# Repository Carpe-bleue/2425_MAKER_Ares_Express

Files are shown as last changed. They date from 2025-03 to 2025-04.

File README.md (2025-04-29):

# 2425_MAKER_Ares_Express
Depository for the "Ares Express" project, within the framework of the Maker option of ENSEA led by M.Papazoglou

Video récapitulative : https://www.youtube.com/watch?v=NGvs9T8YtXU

# Description
The idea of this project is to build a miniature train on rails. It would integrate features like LEDs, sound, moving parts, screen(s), storage capacity, and remote controlled.
The PCB and motors would be placed in the head Wagon in the front and other wagons would be attached to it and could be replaced easily so we would switch them depending what we want the train to do (adding wagons that can contain things or just fun or decorative wagons).
Screenshot from 2025-01-19 17-37-25
from the following video : "https://youtu.be/WkL9zbtfKDo?si=UJvP77D1sXWMVc81"

# For now :
https://github.com/user-attachments/assets/c41e23c4-729e-4bb9-a937-4c54bc4e76e5

# Ideas

- wheels :
- Screenshot from 2025-01-19 16-12-46

- module HC-SR04 (detect obstacles) :
- Screenshot from 2025-01-18 23-15-40
  
- Steam ? :
- Screenshot from 2025-01-18 23-14-02

PCB : moteurs (x2 minimum), battery, communication module (bluetooth ?), ultrasound module, screen, actuators, module that make sound ?, LEDs, electro-magnets ?, accelerometers, 

electromagnets to attach/detach wagons !
Camera ?

- details : angry eyebrows, ares logo, small characters ?
Difficult ideas : A claw to move an object from the tracks, mapping room with lidar, putting tracks before itself, Stations

# Planning :

- 3d Model, 1st wagon : 23 janvier
- Printing 1st Wagon : 23-27 janvier
- PCB : 10 février

- Vacation : Models for Head wagon and rails

- 1st rail (laser) : 3 mars
- Head wagon model : 10 mars
- Printing head Wagon : 13 mars
- Test of head wagon with PCB : 17 mars 
- Complete track (laser cut wood) : 20 mars-24 mars
- Soft (screen, LEDs, communication) : 27 mars - 4 avril

Module Hc-sr04 :


Module Hc-05 : 


Module Caméra ? :


Potentially useful regulator : 


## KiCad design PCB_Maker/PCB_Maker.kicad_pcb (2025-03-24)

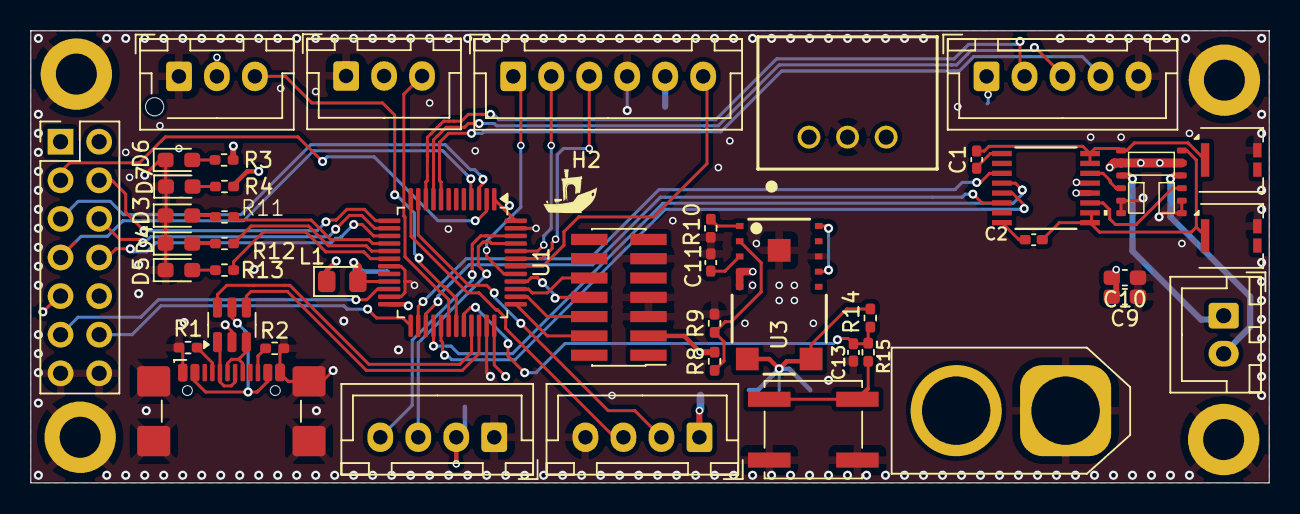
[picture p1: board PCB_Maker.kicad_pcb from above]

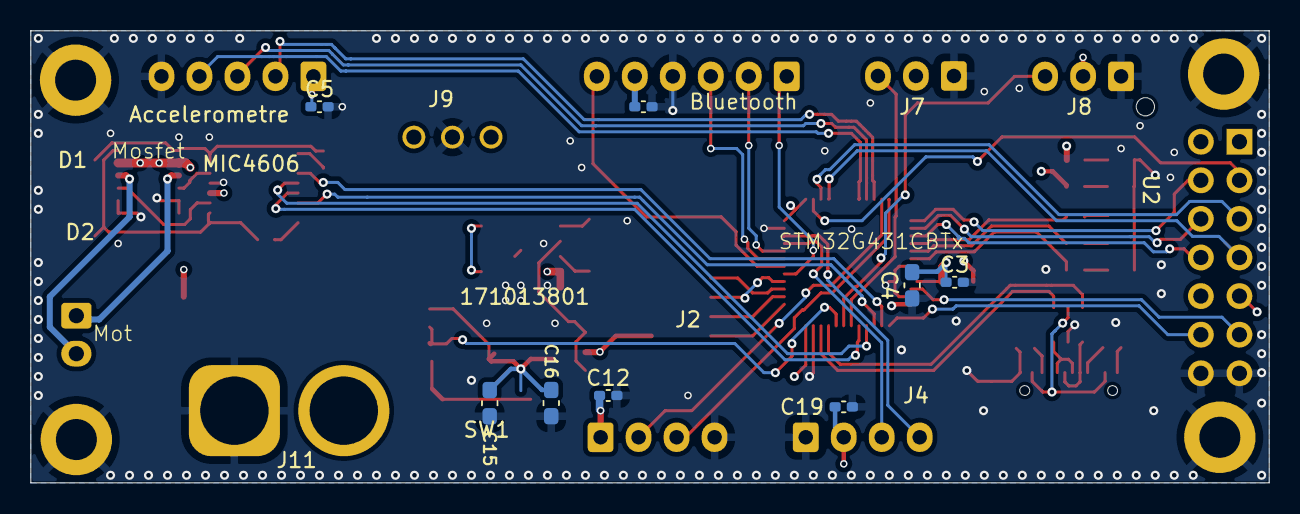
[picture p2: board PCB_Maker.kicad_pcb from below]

Board: 4 copper layers, 81.5 x 29.8 mm, 56 parts (8 on the bottom side), 63 nets.

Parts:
C1, C2, C5, C6, C11, C12, C19: 1u; C_0402_1005Metric_Pad0.74x0.62mm_HandSolder
C3, C13: 10n; C_0402_1005Metric_Pad0.74x0.62mm_HandSolder
C4: 1u; C_0603_1608Metric_Pad1.08x0.95mm_HandSolder
C9: 22u; C_0603_1608Metric_Pad1.08x0.95mm_HandSolder
C10: 10u; C_0603_1608Metric_Pad1.08x0.95mm_HandSolder
C15, C16: 100n; C_0603_1608Metric_Pad1.08x0.95mm_HandSolder
D1, D2: D_Zener; Littelfuse_PolyZen-LS
D3, D4, D5: LED_GREEN; LED_0603_1608Metric_Pad1.05x0.95mm_HandSolder
D6: RED_LED_5V; LED_0603_1608Metric_Pad1.05x0.95mm_HandSolder
D7: RED_LED_3.3V; LED_0603_1608Metric_Pad1.05x0.95mm_HandSolder
H1, H2, H3, H4: MountingHole_Pad; MountingHole_2.7mm_M2.5_DIN965_Pad
J1: USB_C_Receptacle_USB2.0_16P; USB_C_Receptacle_GCT_USB4110
J2: Conn_ST_STDC14; PinHeader_2x07_P1.27mm_Vertical_SMD
J3: Conn_01x02; JST_XH_B2B-XH-A_1x02_P2.50mm_Vertical
J4, J5: Conn_01x04; JST_XH_B4B-XH-A_1x04_P2.50mm_Vertical
J6: Conn_01x05; JST_XH_B5B-XH-A_1x05_P2.50mm_Vertical
J7: Conn_01x03; JST_XH_B3B-XH-A_1x03_P2.50mm_Vertical
J8: Conn_01x03; JST_XH_B3B-XH-AM_1x03_P2.50mm_Vertical
J9: 173010542; 173013542
J10: Conn_02x07_Odd_Even; PinHeader_2x07_P2.54mm_Vertical
J11: Conn_01x02; AMASS_XT60-F_1x02_P7.20mm_Vertical
J12: Conn_01x06; JST_XH_B6B-XH-A_1x06_P2.50mm_Vertical
L1: 39n; LED_0805_2012Metric_Pad1.15x1.40mm_HandSolder
MIC4606: TSSOP16_TS_MCH_MIS
Mosfet_canal_N1: FDMQ86530L
R1, R2: 5.1k; R_0402_1005Metric_Pad0.72x0.64mm_HandSolder
R3: 3k6; R_0402_1005Metric_Pad0.72x0.64mm_HandSolder
R4, R11, R12, R13: 1k6; R_0402_1005Metric_Pad0.72x0.64mm_HandSolder
R8: 287k; R_0402_1005Metric_Pad0.72x0.64mm_HandSolder
R9: 137k; R_0402_1005Metric_Pad0.72x0.64mm_HandSolder
R10: 5.6k; R_0402_1005Metric_Pad0.72x0.64mm_HandSolder
R14, R15: 10k; R_0402_1005Metric_Pad0.72x0.64mm_HandSolder
SW1: SW_Push; SW_Push_1P1T_NO_CK_KSC6xxJ
U1: STM32G431CBTx; LQFP-48_7x7mm_P0.5mm
U2: USBLC6-2SC6; SOT-23-6
U3: 171013801; 171023801

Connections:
+3.3V: C12.1, C15.1, C16.1, C19.1, J2.3 (VCC), J4.2, J5.1, J10.9, J10.10, L1.1, R4.1, R8.1, R14.1, U1.1 (VBAT), U1.24 (VDD), U1.36 (VDD), U1.48 (VDD), U3.6, U3.7
+3.3VA: C3.1, C4.1, L1.2, U1.21 (VDDA)
+5V: C5.1, C6.1, J6.1, J7.2, J8.2, J9.3 (VOUT), J10.1, J10.2, J12.5, R3.1
/ADC_accelerometer_X: J6.2, U1.10 (PA2)
/ADC_accelerometer_Y: J6.3, U1.9 (PA1)
/ADC_accelerometer_Z: J6.4, U1.8 (PA0)
/D+: J1.A6 (D+), J1.B6 (D+), U2.3 (I/O2)
/D-: J1.A7 (D-), J1.B7 (D-), U2.1 (I/O1)
/EN_Bluetooth: J12.6, U1.42 (PB5)
/Echo_HC_SR04: J5.3, U1.12 (PA4)
/GPIO_filtered: C13.1, R14.2, R15.1, U1.32 (PA10)
/I2C1_SCL: J4.3, U1.45 (PB8)
/I2C1_SDA: J4.4, U1.46 (PB9)
/PA_5: J10.4, U1.13 (PA5)
/PA_6: J10.6, U1.14 (PA6)
/PA_7: J10.8, U1.15 (PA7)
/PB0_LED_1: R11.1, U1.16 (PB0)
/PB1_LED_2: R12.1, U1.17 (PB1)
/PB2_LED_3: R13.1, U1.18 (PB2)
/PB_10: J10.11, U1.22 (PB10)
/PB_11: J10.12, U1.25 (PB11)
/PC_13: J10.3, U1.2 (PC13)
/PC_14: J10.5, U1.3 (PC14)
/PC_15: J10.7, U1.4 (PC15)
/PWM_TIM1_CH1: J7.3, U1.30 (PA8)
/PWM_TIM1_CH2: J8.3, U1.31 (PA9)
/STATE_Bluetooth: J12.1, U1.41 (PB4)
/Trig_HC-SR04: J5.2, U1.11 (PA3)
/USART1_RX: J12.2, U1.44 (PB7)
/USART1_TX: J12.3, U1.43 (PB6)
/USB_DM: U1.33 (PA11), U2.6 (I/O1)
/USB_DP: U1.34 (PA12), U2.4 (I/O2)
/V_USB: J1.A4 (VBUS), J1.A9 (VBUS), J1.B4 (VBUS), J1.B9 (VBUS), U2.5 (VBUS)
AHI: MIC4606.6 (AHI), U1.27 (PB13)
AHO: C2.1, D2.1 (K), MIC4606.9 (AHO), MIC4606.10 (AHS), Mosfet_canal_N1.12 (G4)
ALI: MIC4606.5 (ALI), U1.29 (PB15)
ALO: MIC4606.11 (ALO), Mosfet_canal_N1.9 (G3)
BHI: MIC4606.3 (BHI), U1.26 (PB12)
BHO: C1.1, D1.1 (K), MIC4606.15 (BHS), MIC4606.16 (BHO), Mosfet_canal_N1.1 (G1)
BLI: MIC4606.4 (BLI), U1.28 (PB14)
BLO: MIC4606.14 (BLO), Mosfet_canal_N1.4 (G2)
GND: C3.2, C4.2, C5.2, C6.2, C9.1, C10.1, C11.2, C12.2, C13.2, C15.2, C16.2, C19.2, D1.2 (A), D2.2 (A), D3.1 (K), D4.1 (K), D5.1 (K), D6.1 (K), D7.1 (K), H1.1, H2.1, H3.1, H4.1, J1.A1 (GND), J1.A12 (GND), J1.B1 (GND), J1.B12 (GND), J1.S1 (SHIELD), J2.5 (GND), J2.7 (GND), J2.11 (GNDDetect), J4.1, J5.4, J6.5, J7.1, J8.1, J9.2 (GND), J10.13, J10.14, J11.1, J12.4, MIC4606.13 (VSS), Mosfet_canal_N1.5 (S2), Mosfet_canal_N1.6 (S2), Mosfet_canal_N1.7 (S3), Mosfet_canal_N1.8 (S3), R1.2, R2.2, R9.2, R10.1, SW1.2, U1.19 (VSSA), U1.23 (VSS), U1.35 (VSS), U1.47 (VSS), U2.2 (GND), U3.10, U3.EP
JTDI: J2.10 (JTDI/NC), U1.39 (PA15)
MOT_1: J3.1, Mosfet_canal_N1.3 (S1/D2)
MOT_2: J3.2, Mosfet_canal_N1.10 (D3/S4)
unnamed: C11.1, U3.3
unnamed: D3.2 (A), R11.2
unnamed: D4.2 (A), R12.2
unnamed: D5.2 (A), R13.2
unnamed: D6.2 (A), R3.2
unnamed: D7.2 (A), R4.2
unnamed: J1.A5 (CC1), R1.1
unnamed: J1.B5 (CC2), R2.1
unnamed: C2.2, MIC4606.8 (AHB)
unnamed: C1.2, MIC4606.1 (BHB)
unnamed: R8.2, R9.1, U3.2
unnamed: R10.2, U3.1
unnamed: R15.2, SW1.1
unnamed: U3.9, U3.12
SWCLK: J2.6 (JCLK/SWCLK), U1.38 (PA14)
SWDIO: J2.4 (JTMS/SWDIO), U1.37 (PA13)
SWO: J2.8 (JTDO/SWO), U1.40 (PB3)
VCC: C9.2, C10.2, J9.1 (VIN), J11.2, MIC4606.12 (VDD), Mosfet_canal_N1.2 (D1/D4), Mosfet_canal_N1.11 (D1/D4), U3.4, U3.5

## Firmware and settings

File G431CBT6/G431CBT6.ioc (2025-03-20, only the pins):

Mcu.UserName=STM32G431CBTx
PA0.Signal=ADC1_IN1
PA1.Signal=ADC1_IN2
PA10.Signal=GPIO_Output
PA11.Signal=USB_DM
PA12.Signal=USB_DP
PA13.Signal=SYS_JTMS-SWDIO
PA14.Signal=SYS_JTCK-SWCLK
PA15.Signal=SYS_JTDI
PA2.Signal=ADC1_IN3
PA3.GPIO_Label=Trig
PA3.Signal=S_TIM2_CH4
PA4.GPIO_Label=Echo
PA4.Signal=S_TIM3_CH2
PA5.Signal=GPIO_Output
PA6.Signal=GPIO_Output
PA7.Signal=GPIO_Output
PA8.GPIO_Label=AHI
PA8.Signal=S_TIM1_CH1
PA9.GPIO_Label=BHI
PA9.Signal=S_TIM1_CH2
PB0.GPIO_Label=LED1
PB0.Signal=GPIO_Output
PB1.GPIO_Label=LED2
PB1.Signal=GPIO_Output
PB10.Signal=GPIO_Output
PB11.Signal=GPIO_Output
PB12.Signal=GPIO_Output
PB13.GPIO_Label=ALI
PB13.Signal=TIM1_CH1N
PB14.GPIO_Label=BLI
PB14.Signal=TIM1_CH2N
PB15.Signal=GPIO_Output
PB2.GPIO_Label=LED3
PB2.Signal=GPIO_Output
PB3.Signal=SYS_JTDO-SWO
PB4.GPIO_Label=State_Bluetooth
PB4.Signal=GPIO_Input
PB5.GPIO_Label=EN_Blutooth
PB5.Signal=GPIO_Output
PB6.Signal=USART1_TX
PB7.Signal=USART1_RX
PB8-BOOT0.Signal=I2C1_SCL
PB9.Signal=I2C1_SDA
PC13.Signal=GPIO_Output
PC14-OSC32_IN.Signal=GPIO_Output
PC15-OSC32_OUT.Signal=GPIO_Output

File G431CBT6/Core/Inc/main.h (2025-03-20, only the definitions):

#define Trig_Pin GPIO_PIN_3
#define Trig_GPIO_Port GPIOA
#define Echo_Pin GPIO_PIN_4
#define Echo_GPIO_Port GPIOA
#define LED1_Pin GPIO_PIN_0
#define LED1_GPIO_Port GPIOB
#define LED2_Pin GPIO_PIN_1
#define LED2_GPIO_Port GPIOB
#define LED3_Pin GPIO_PIN_2
#define LED3_GPIO_Port GPIOB
#define ALI_Pin GPIO_PIN_13
#define ALI_GPIO_Port GPIOB
#define BLI_Pin GPIO_PIN_14
#define BLI_GPIO_Port GPIOB
#define AHI_Pin GPIO_PIN_8
#define AHI_GPIO_Port GPIOA
#define BHI_Pin GPIO_PIN_9
#define BHI_GPIO_Port GPIOA
#define State_Bluetooth_Pin GPIO_PIN_4
#define State_Bluetooth_GPIO_Port GPIOB
#define EN_Blutooth_Pin GPIO_PIN_5
#define EN_Blutooth_GPIO_Port GPIOB

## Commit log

2025-03-19 PCB improve
    [PCB_Maker.kicad_pcb, PCB_Maker.kicad_sch, PCB_Train.kicad_pcb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]
2025-03-20 pcb correction
    [PCB_Maker.kicad_pcb]
2025-03-24 PCB correction Mr.Papazoglou
    [PCB_Maker.kicad_pcb, PCB_Maker.kicad_sch, motor_control.kicad_sch]

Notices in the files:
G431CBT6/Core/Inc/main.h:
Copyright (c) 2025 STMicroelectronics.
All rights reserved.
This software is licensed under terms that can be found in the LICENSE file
